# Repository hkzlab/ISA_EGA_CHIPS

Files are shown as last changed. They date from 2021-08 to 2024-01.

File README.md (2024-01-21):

# Enhanced Graphics Adapter

## Introduction

This board is and EGA clone based on a reversed **PA-WTEGA** card, based on the chipset by **CHIPS** (P82C435 + P82A436). 

The chipset should be compatible with EGA, CGA, MDA and Hercules standards.

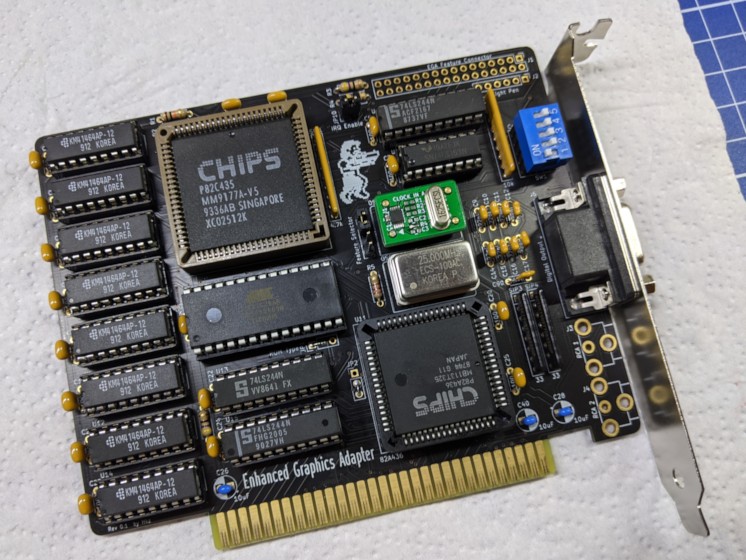
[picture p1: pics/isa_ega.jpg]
EGA CHIPS


### Disclaimer

I take NO responsibility for what happens if you decide to build and use this card. Your computer might crash, catch fire or be destroyed in other nasty ways.
You're encourauged to take what you deem fit from this, and use it in your projects!

### Configuration

The card as a bank of 5 dipswitches. Dipswitch 1-4 select the card video output mode, dipswitch 5 selects the IO address.

0 means switch open, 1 means closed.

* Jumpers 1-4:
    * 0-1-0-0: MDA Mode (main)
    * 1-0-0-1: CGA 40x25 (main)
    * 1-0-0-0: CGA 80x25 (main)
    * 0-1-1-1: EGA 200 lines (main)
    * 0-1-1-0: EGA 350 lines (main)
    * 1-1-1-1: CGA 40x25 (secondary)
    * 1-1-1-0: CGA 80x25 (secondary)
    * 1-1-0-1: EGA 200 lines (secondary)
    * 1-1-0-0: EGA 350 lines (secondary)
* Jumper 5:
    * 0: I/O address range in 3xx **default**
    * 1: I/O address range in 2xx

**NOTE:** The meaning of each combination is dependant on the bios of the card. This list was taken from the TEVA-2 card's manual.

TODO: Test all the combinations provided in the TEVA-2 card manual

### Functionalities

✅ means I tested the functionality and it works, ❌ means I tested the functionality and found issues, ? means that the functionality has yet to be tested.

* [✅] Display checkup with CheckIt (5154/EGA monitor)
* [✅] Display checkup with CheckIt (5153/CGA monitor)
* [?] Display checkup with CheckIt (5151/MDA monitor)
* [?] Display checkup with CheckIt (Hercules mode)
* [?] Feature Connector
* [?] Light pen input

## Bill of Materials

| Component | Qty | Type / Value |
| --- | --- | --- |
| **TODO** | | |

You can hardwire `JP1` pins 1-2 and `JP2` pins 2-3.

Connectors `RCA 1` and `RCA 2` are useless unless an expansion for the feature connector is used. You can leave them out.

### BIOS

This board was tested with [Phoenix Video Bios V1.02 for P82C435](bios/Phoenix_video_bios_PA-WTEGA_NMC27C256Q.BIN).

Burn it on a 27C256 and plug it in U10.

### Component substitutions

* U15 and U13 can be substituted with HCT equivalents
* U4 is an 'LS244 in the original card, I noticed an improvement in image stability with a MCE2VGA by using an 'F244 

## Known issues

### General issues

These are issues found with this board, but that are **also present in the original model** I cloned.

* Screen tearing detected in Commander Keen 4 and 5 (also happening on DOSBox configured for EGA, also note [here](http://nerdlypleasures.blogspot.com/2014/09/how-many-fps-dos-games-and-framerates.html): `The use of 35 frames, even in a 16-color game like Keen, demonstrates that ID was using VGA, not EGA, to develop the game` ). It can be fixed in-game by enabling the "Fix Jerky Motion" option in the config screen.
* Minor graphical glitches (flickering at top of the screen) during gameplay in Tom & Jerry CAT-astrophe.

### Rev 0.1

* Not really an issue as this is not present in the original card I cloned, but might be worth to add a jumper that can physically connect pin 2 of the DB9 connector to GND and not rely only on the jumper configuration, when using the card with a CGA monitor.

### Rev 0

* Some traces stub are left near the edge connector
* Some traces for sensitive sync signals are routed under the oscillators

## TODO

* Testing...

## Credits

Thanks to [Sergey Kiselev](https://github.com/skiselev) for his symbol/footprint library!

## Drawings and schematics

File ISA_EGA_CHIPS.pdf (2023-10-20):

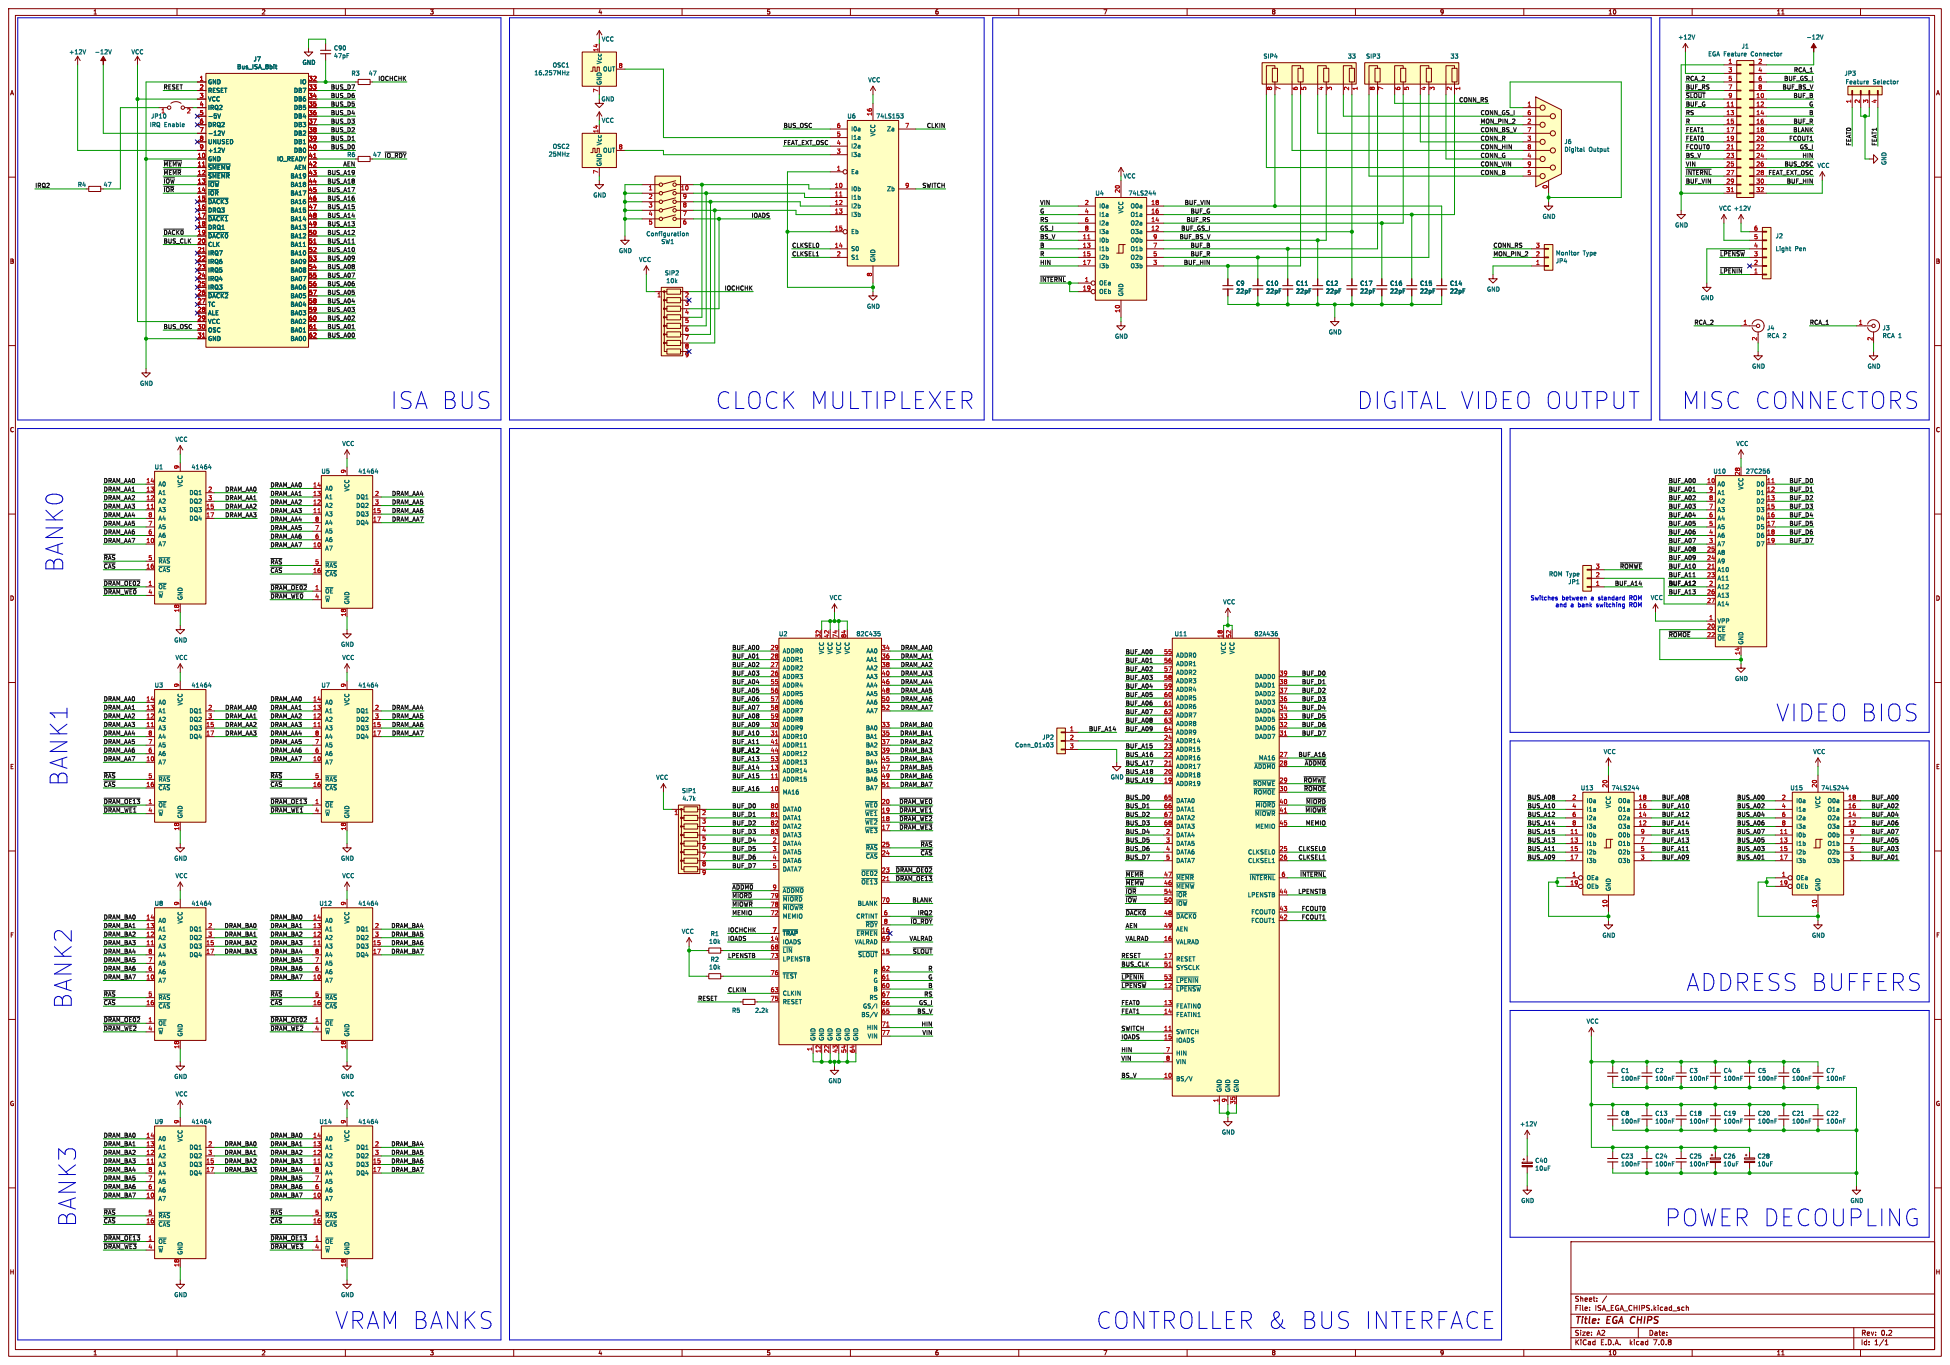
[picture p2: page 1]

J7 Bus_ISA_8bit GND 1 GND 10 ~{SMEMW} 11 ~{SMEMR} 12 ~{IOW} 13 ~{IOR} 14 ~{DACK3} 15 DRQ3 16 ~{DACK1} 17 DRQ1 18 ~{DACK0} 19 RESET 2 CLK 20

J1 EGA Feature Connector GND

J7 Bus_ISA_8bit
IRQ3 25 ~{DACK2} 26 TC 27 ALE 28 VCC 29 VCC 3 OSC 30 GND 31

JP3 Feature Selector GND

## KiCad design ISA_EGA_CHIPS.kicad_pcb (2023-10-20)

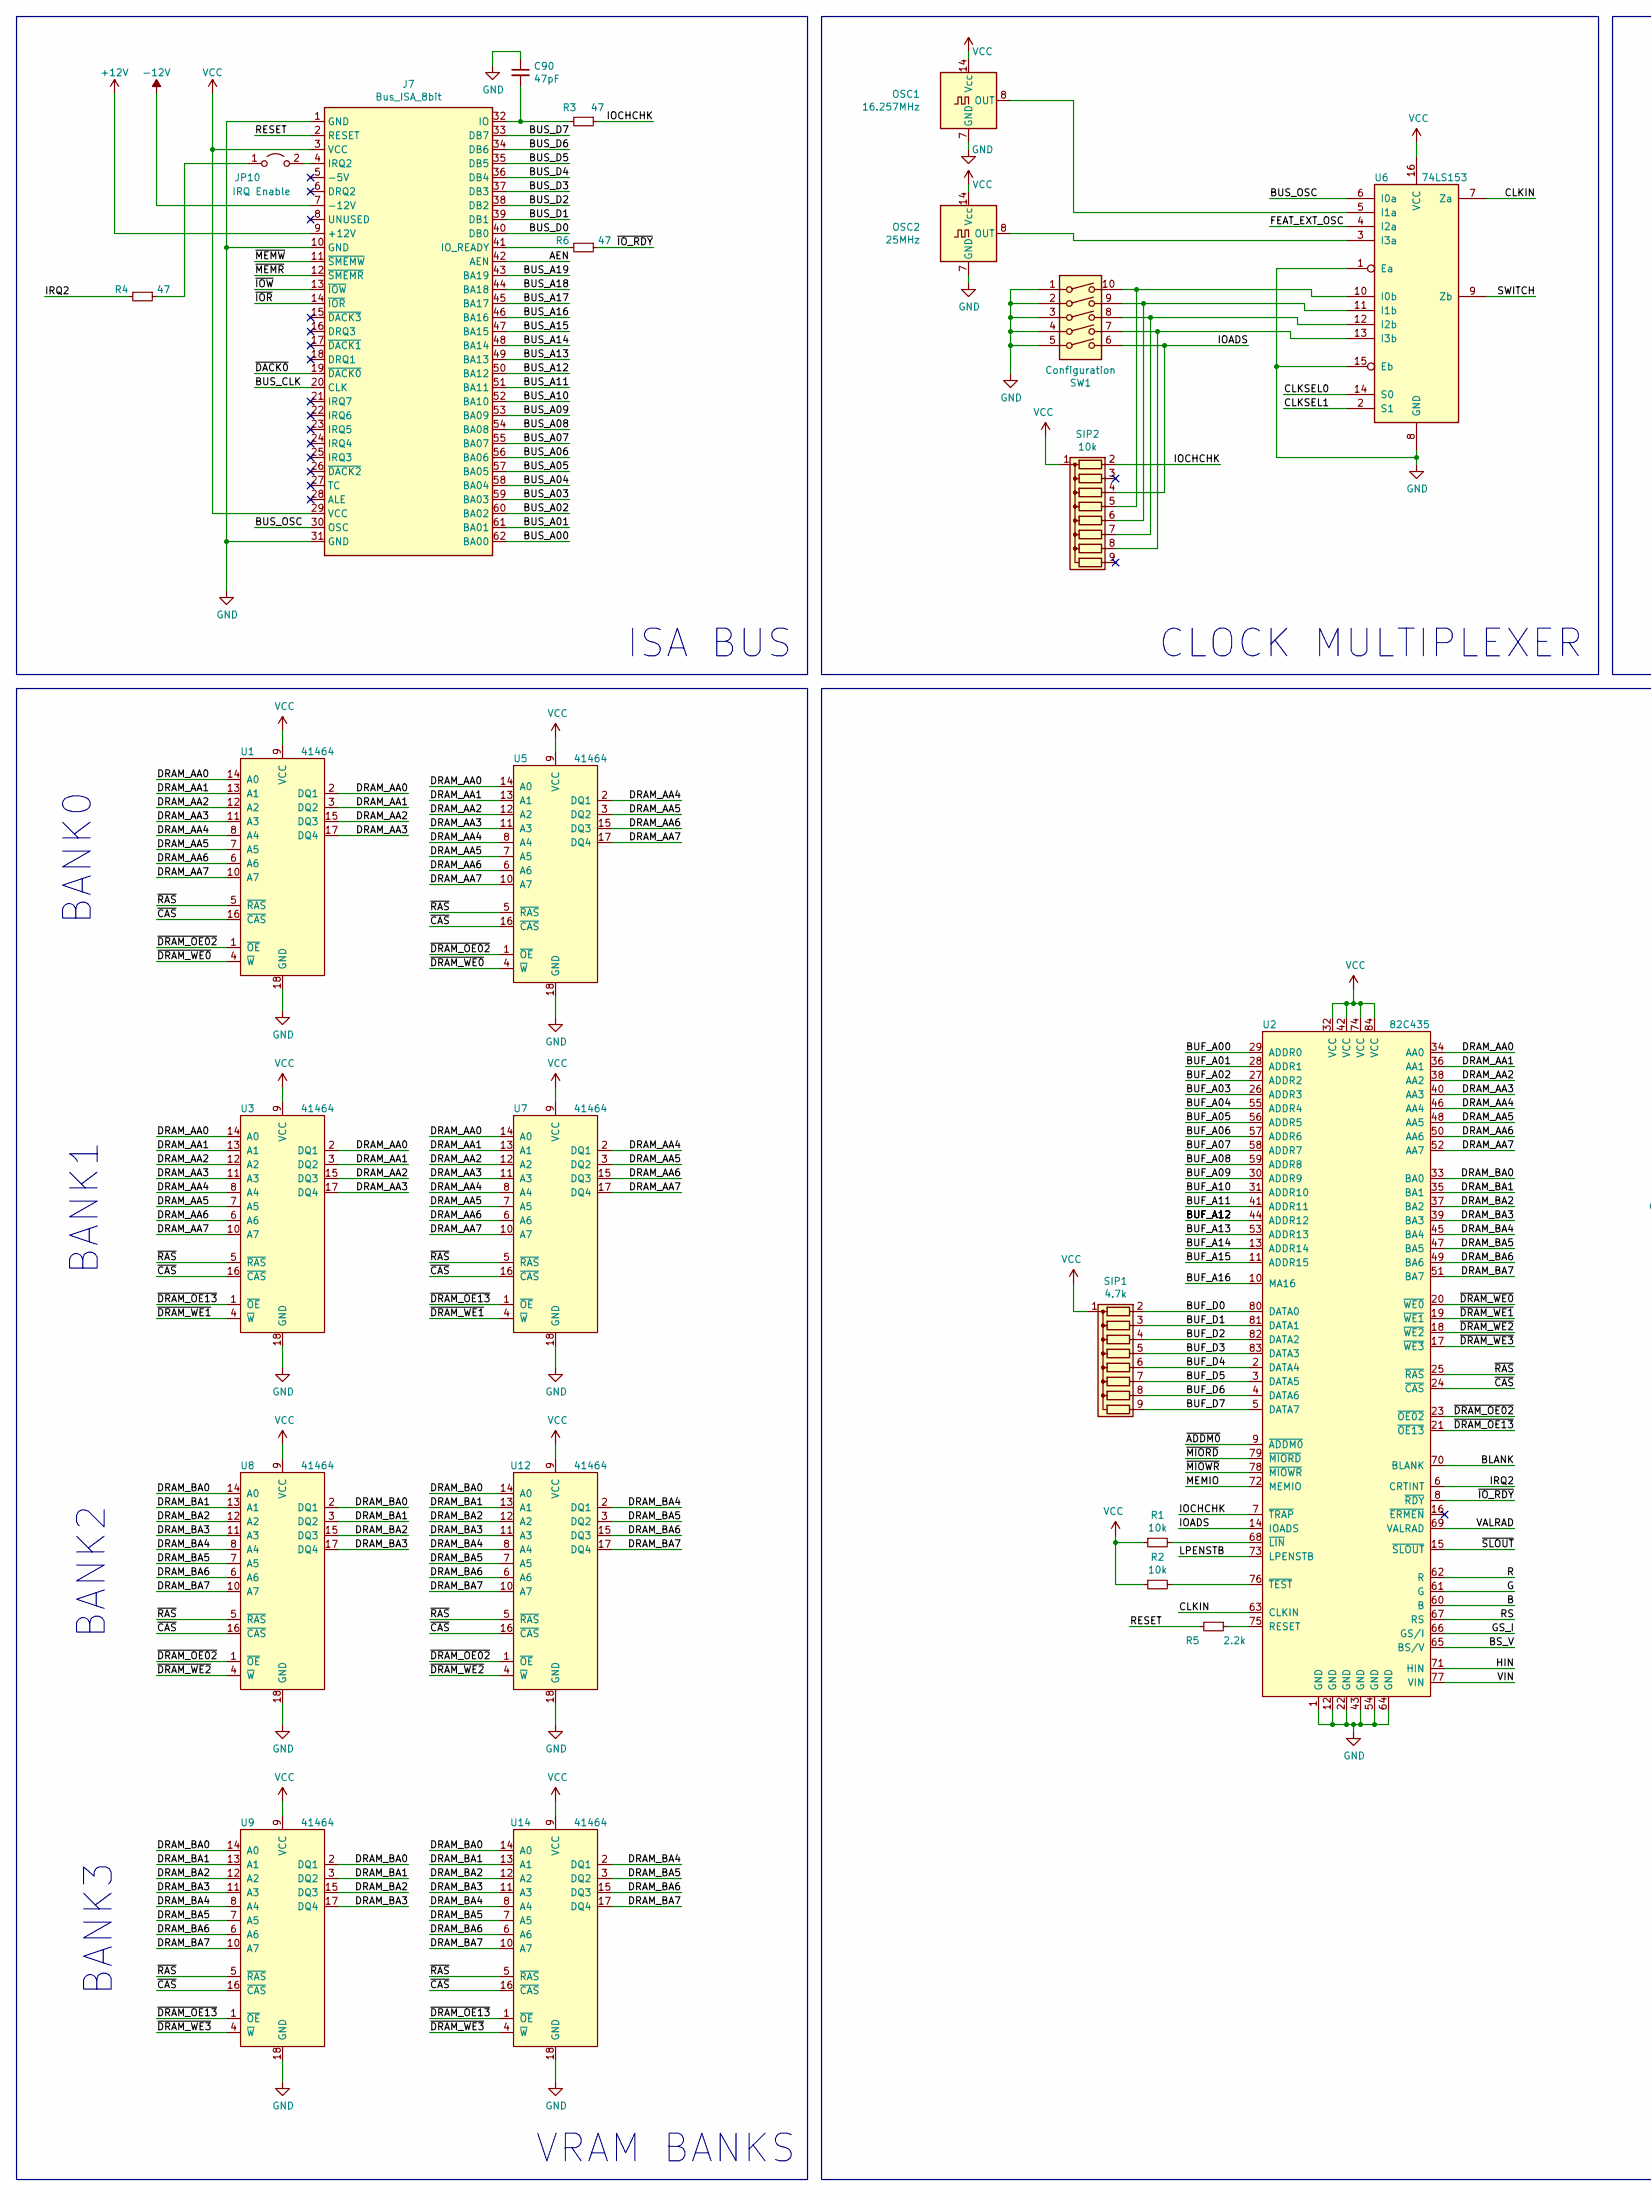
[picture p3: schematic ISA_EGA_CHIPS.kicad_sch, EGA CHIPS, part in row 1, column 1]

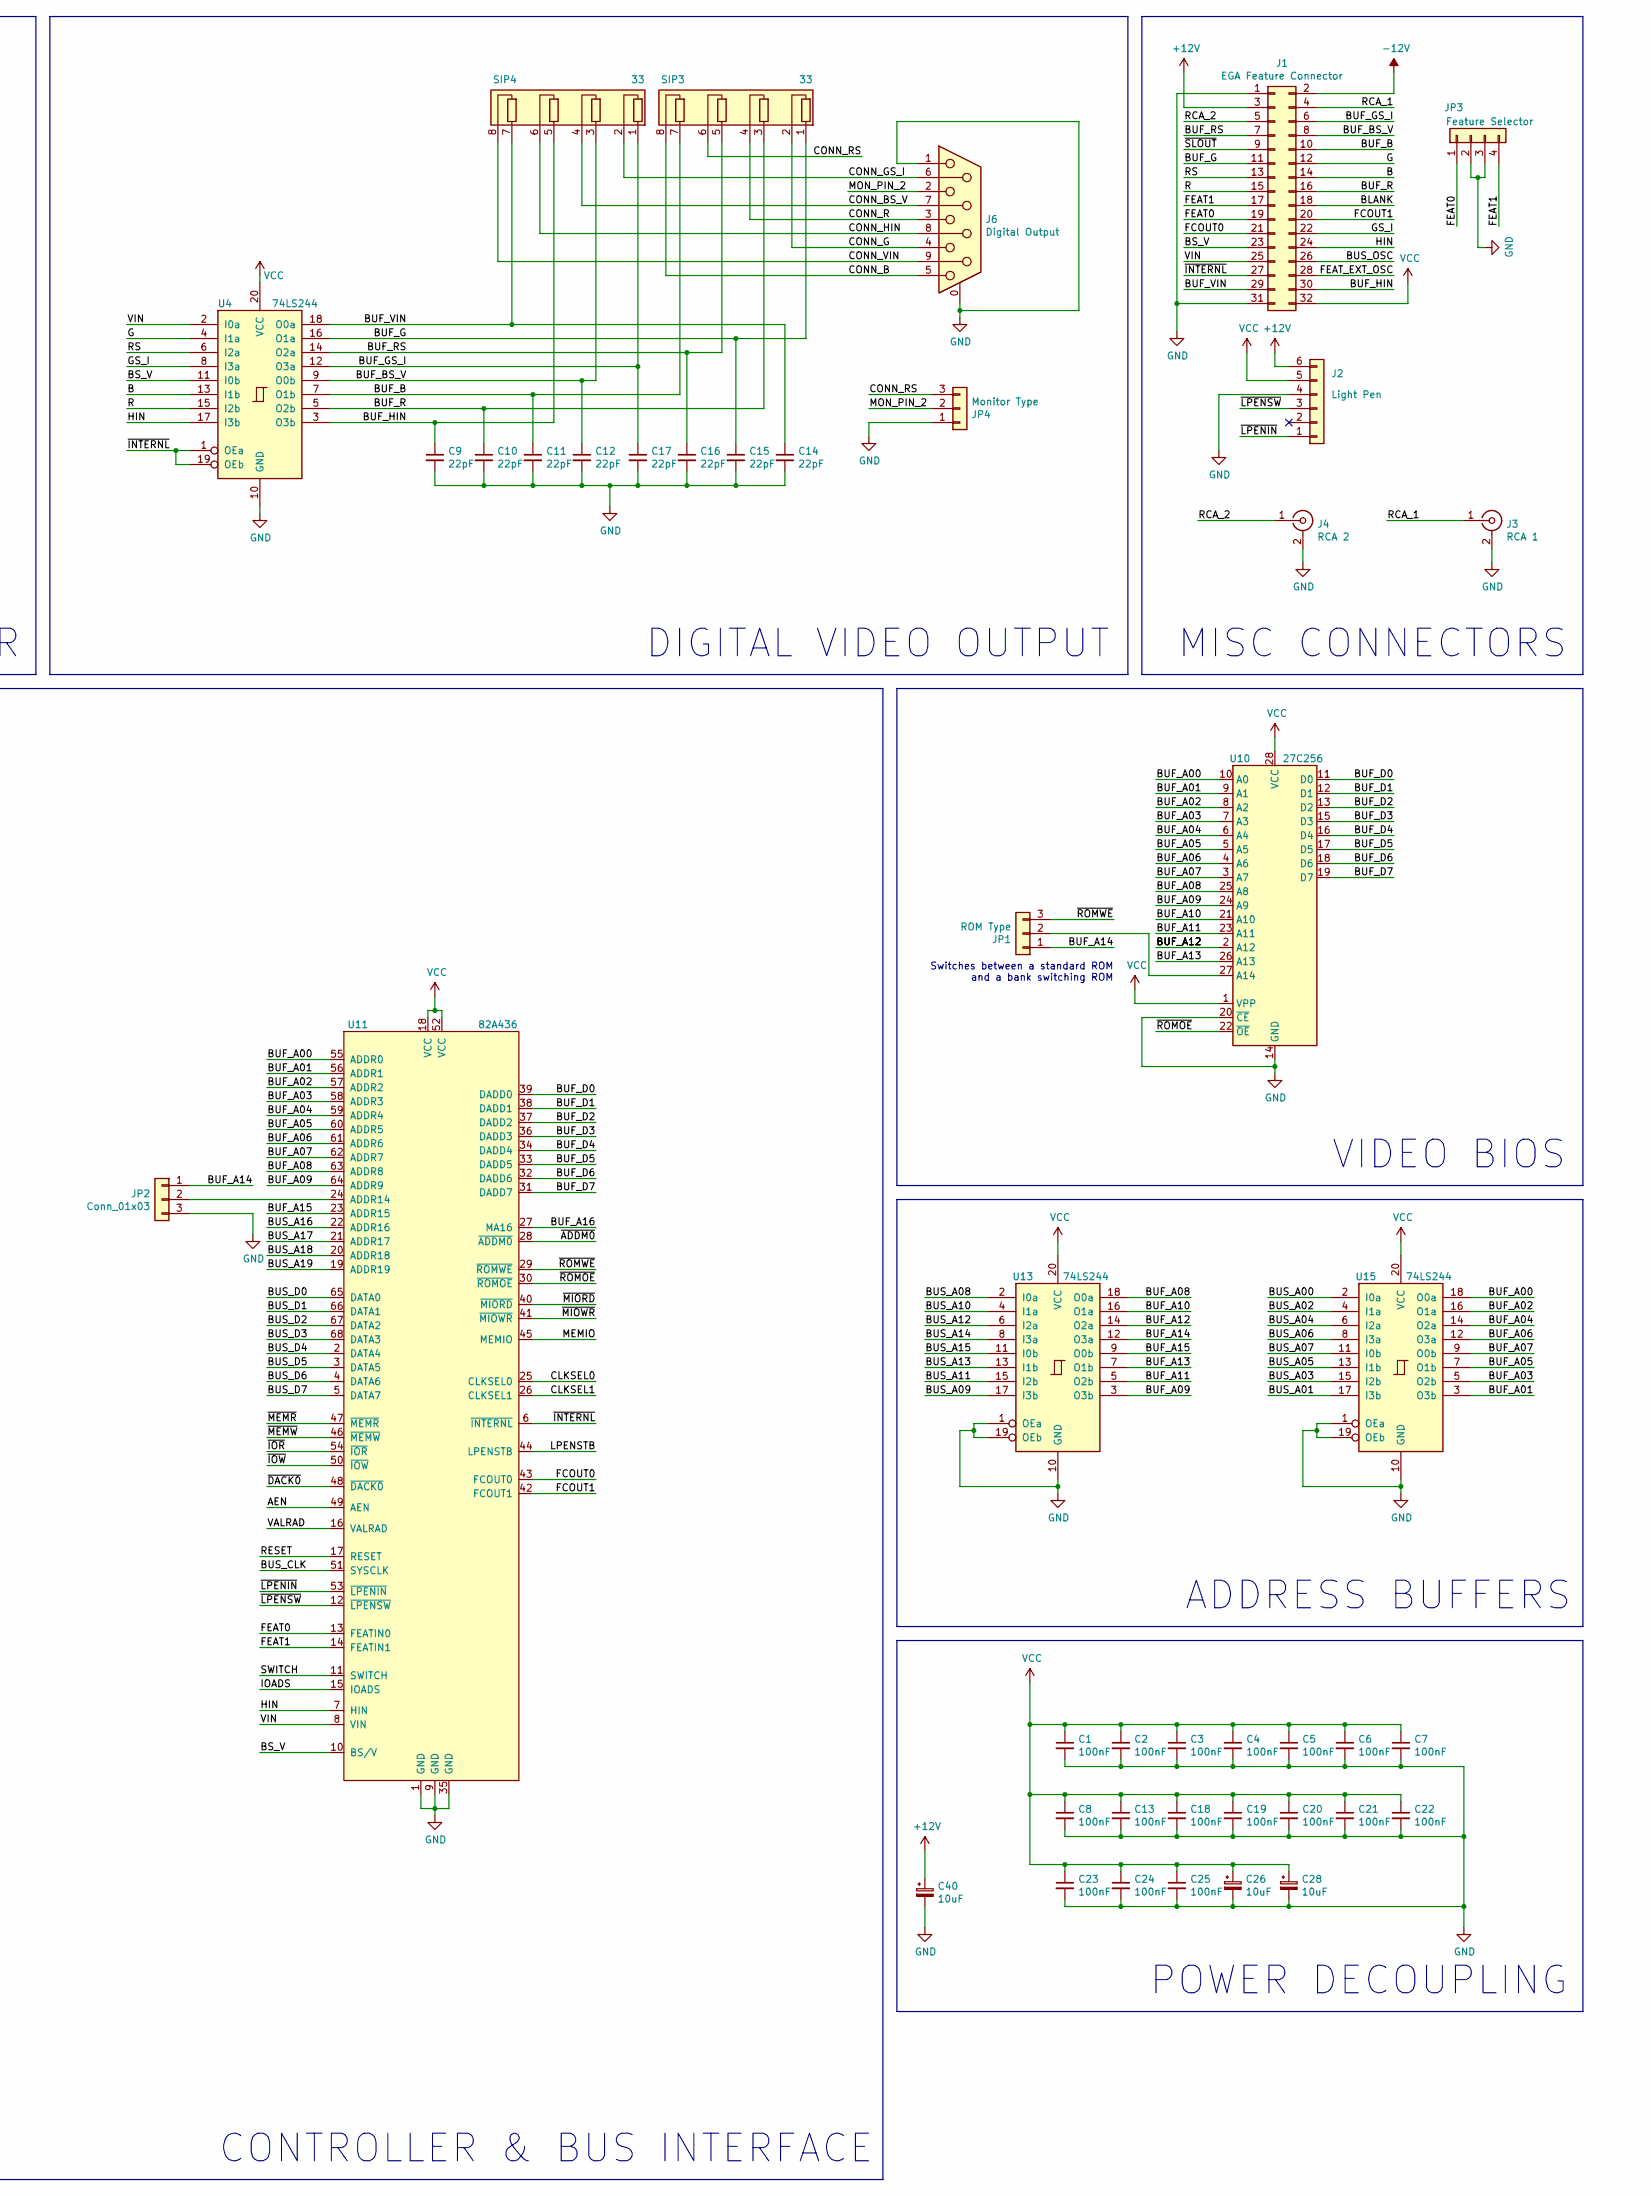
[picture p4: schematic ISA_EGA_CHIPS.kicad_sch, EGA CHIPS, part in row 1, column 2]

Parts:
C1, C2, C3, C4, C5, C6, C7, C8, C13, C18, C19, C20, C21, C22, C23, C24, C25: 100nF; C_Disc_D4.3mm_W1.9mm_P5.00mm
C9, C10, C11, C12, C14, C15, C16, C17: 22pF; C_Disc_D4.3mm_W1.9mm_P5.00mm
C26, C28, C40: 10uF; CP_Radial_D5.0mm_P2.50mm
C90: 47pF; C_Disc_D4.3mm_W1.9mm_P5.00mm
J1: EGA Feature Connector; PinHeader_2x16_P2.54mm_Vertical
J2: Light Pen; PinHeader_1x06_P2.54mm_Vertical
J3: RCA 1; Conn_RCA_Right
J4: RCA 2; Conn_RCA_Right
J6: Digital Output; DSUB-9_Female_Horizontal_P2.77x2.84mm_EdgePinOffset7.70mm_H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
J7: Bus_ISA_8bit; Conn_Edge_PCB_ISA8
JP1: ROM Type; PinHeader_1x03_P2.54mm_Vertical
JP2: Conn_01x03; PinHeader_1x03_P2.54mm_Vertical
JP3: Feature Selector; PinHeader_1x04_P2.54mm_Vertical
JP4: Monitor Type; PinHeader_1x03_P2.54mm_Vertical
JP10: IRQ Enable; PinHeader_1x02_P2.54mm_Vertical
OSC1: 16.257MHz; Oscillator_DIP-14-8
OSC2: 25MHz; Oscillator_DIP-14-8
R1, R2: 10k; R_Axial_DIN0207_L6.3mm_D2.5mm_P7.62mm_Horizontal
R3, R4, R6: 47; R_Axial_DIN0207_L6.3mm_D2.5mm_P7.62mm_Horizontal
R5: 2.2k; R_Axial_DIN0207_L6.3mm_D2.5mm_P7.62mm_Horizontal
SIP1: 4.7k; R_Array_SIP9
SIP2: 10k; R_Array_SIP9
SIP3, SIP4: 33; R_Array_SIP8
SW1: Configuration; DIP-10_W7.62mm_Socket
U1, U3, U5, U7, U8, U9, U12, U14: 41464; DIP-18_W7.62mm
U2: 82C435; PLCC-84_THT-Socket
U4, U13, U15: 74LS244; DIP-20_W7.62mm
U6: 74LS153; DIP-16_W7.62mm
U10: 27C256; DIP-28_W15.24mm
U11: 82A436; PLCC-68_THT-Socket

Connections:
+12V: C40.1, J1.3, J2.6, J7.9 (+12V)
-12V: J1.2, J7.7 (-12V)
/AEN: J7.42 (AEN), U11.49 (AEN)
/B: J1.14, U2.60 (B), U4.13 (I1b)
/BLANK: J1.18, U2.70 (BLANK)
/BS_V: J1.23, U2.65 (BS/V), U4.11 (I0b), U11.10 (BS/V)
/BUF_A00: U2.29 (ADDR0), U10.10 (A0), U11.55 (ADDR0), U15.18 (O0a)
/BUF_A01: U2.28 (ADDR1), U10.9 (A1), U11.56 (ADDR1), U15.3 (O3b)
/BUF_A02: U2.27 (ADDR2), U10.8 (A2), U11.57 (ADDR2), U15.16 (O1a)
/BUF_A03: U2.26 (ADDR3), U10.7 (A3), U11.58 (ADDR3), U15.5 (O2b)
/BUF_A04: U2.55 (ADDR4), U10.6 (A4), U11.59 (ADDR4), U15.14 (O2a)
/BUF_A05: U2.56 (ADDR5), U10.5 (A5), U11.60 (ADDR5), U15.7 (O1b)
/BUF_A06: U2.57 (ADDR6), U10.4 (A6), U11.61 (ADDR6), U15.12 (O3a)
/BUF_A07: U2.58 (ADDR7), U10.3 (A7), U11.62 (ADDR7), U15.9 (O0b)
/BUF_A08: U2.59 (ADDR8), U10.25 (A8), U11.63 (ADDR8), U13.18 (O0a)
/BUF_A09: U2.30 (ADDR9), U10.24 (A9), U11.64 (ADDR9), U13.3 (O3b)
/BUF_A10: U2.31 (ADDR10), U10.21 (A10), U13.16 (O1a)
/BUF_A11: U2.41 (ADDR11), U10.23 (A11), U13.5 (O2b)
/BUF_A12: U2.44 (ADDR12), U10.2 (A12), U13.14 (O2a)
/BUF_A13: U2.53 (ADDR13), U10.26 (A13), U13.7 (O1b)
/BUF_A14: JP1.1, JP2.1, U2.13 (ADDR14), U13.12 (O3a)
/BUF_A15: U2.11 (ADDR15), U11.23 (ADDR15), U13.9 (O0b)
/BUF_A16: U2.10 (MA16), U11.27 (MA16)
/BUF_B: C11.1, J1.10, SIP3.7 (R4.1), U4.7 (O1b)
/BUF_BS_V: C12.1, J1.8, SIP4.3 (R2.1), U4.9 (O0b)
/BUF_D0: SIP1.2 (R1), U2.80 (DATA0), U10.11 (D0), U11.39 (DADD0)
/BUF_D1: SIP1.3 (R2), U2.81 (DATA1), U10.12 (D1), U11.38 (DADD1)
/BUF_D2: SIP1.4 (R3), U2.82 (DATA2), U10.13 (D2), U11.37 (DADD2)
/BUF_D3: SIP1.5 (R4), U2.83 (DATA3), U10.15 (D3), U11.36 (DADD3)
/BUF_D4: SIP1.6 (R5), U2.2 (DATA4), U10.16 (D4), U11.34 (DADD4)
/BUF_D5: SIP1.7 (R6), U2.3 (DATA5), U10.17 (D5), U11.33 (DADD5)
/BUF_D6: SIP1.8 (R7), U2.4 (DATA6), U10.18 (D6), U11.32 (DADD6)
/BUF_D7: SIP1.9 (R8), U2.5 (DATA7), U10.19 (D7), U11.31 (DADD7)
/BUF_G: C15.1, J1.11, SIP3.1 (R1.1), U4.16 (O1a)
/BUF_GS_I: C17.1, J1.6, SIP4.1 (R1.1), U4.12 (O3a)
/BUF_HIN: C9.1, J1.30, SIP4.5 (R3.1), U4.3 (O3b)
/BUF_R: C10.1, J1.16, SIP3.3 (R2.1), U4.5 (O2b)
/BUF_RS: C16.1, J1.7, SIP3.5 (R3.1), U4.14 (O2a)
/BUF_VIN: C14.1, J1.29, SIP4.7 (R4.1), U4.18 (O0a)
/BUS_A00: J7.62 (BA00), U15.2 (I0a)
/BUS_A01: J7.61 (BA01), U15.17 (I3b)
/BUS_A02: J7.60 (BA02), U15.4 (I1a)
/BUS_A03: J7.59 (BA03), U15.15 (I2b)
/BUS_A04: J7.58 (BA04), U15.6 (I2a)
/BUS_A05: J7.57 (BA05), U15.13 (I1b)
/BUS_A06: J7.56 (BA06), U15.8 (I3a)
/BUS_A07: J7.55 (BA07), U15.11 (I0b)
/BUS_A08: J7.54 (BA08), U13.2 (I0a)
/BUS_A09: J7.53 (BA09), U13.17 (I3b)
/BUS_A10: J7.52 (BA10), U13.4 (I1a)
/BUS_A11: J7.51 (BA11), U13.15 (I2b)
/BUS_A12: J7.50 (BA12), U13.6 (I2a)
/BUS_A13: J7.49 (BA13), U13.13 (I1b)
/BUS_A14: J7.48 (BA14), U13.8 (I3a)
/BUS_A15: J7.47 (BA15), U13.11 (I0b)
/BUS_A16: J7.46 (BA16), U11.22 (ADDR16)
/BUS_A17: J7.45 (BA17), U11.21 (ADDR17)
/BUS_A18: J7.44 (BA18), U11.20 (ADDR18)
/BUS_A19: J7.43 (BA19), U11.19 (ADDR19)
/BUS_CLK: J7.20 (CLK), U11.51 (SYSCLK)
/BUS_D0: J7.40 (DB0), U11.65 (DATA0)
/BUS_D1: J7.39 (DB1), U11.66 (DATA1)
/BUS_D2: J7.38 (DB2), U11.67 (DATA2)
/BUS_D3: J7.37 (DB3), U11.68 (DATA3)
/BUS_D4: J7.36 (DB4), U11.2 (DATA4)
/BUS_D5: J7.35 (DB5), U11.3 (DATA5)
/BUS_D6: J7.34 (DB6), U11.4 (DATA6)
/BUS_D7: J7.33 (DB7), U11.5 (DATA7)
/BUS_OSC: J1.26, J7.30 (OSC), U6.6 (I0a)
/CLKIN: U2.63 (CLKIN), U6.7 (Za)
/CLKSEL0: U6.14 (S0), U11.25 (CLKSEL0)
/CLKSEL1: U6.2 (S1), U11.26 (CLKSEL1)
/CONN_B: J6.5, SIP3.8 (R4.2)
/CONN_BS_V: J6.7, SIP4.4 (R2.2)
/CONN_G: J6.4, SIP3.2 (R1.2)
/CONN_GS_I: J6.6, SIP4.2 (R1.2)
/CONN_HIN: J6.8, SIP4.6 (R3.2)
/CONN_R: J6.3, SIP3.4 (R2.2)
/CONN_RS: JP4.3, SIP3.6 (R3.2)
/CONN_VIN: J6.9, SIP4.8 (R4.2)
/DRAM_AA0: U1.2 (DQ1), U1.14 (A0), U2.34 (AA0), U3.2 (DQ1), U3.14 (A0), U5.14 (A0), U7.14 (A0)
/DRAM_AA1: U1.3 (DQ2), U1.13 (A1), U2.36 (AA1), U3.3 (DQ2), U3.13 (A1), U5.13 (A1), U7.13 (A1)
/DRAM_AA2: U1.12 (A2), U1.15 (DQ3), U2.38 (AA2), U3.12 (A2), U3.15 (DQ3), U5.12 (A2), U7.12 (A2)
/DRAM_AA3: U1.11 (A3), U1.17 (DQ4), U2.40 (AA3), U3.11 (A3), U3.17 (DQ4), U5.11 (A3), U7.11 (A3)
/DRAM_AA4: U1.8 (A4), U2.46 (AA4), U3.8 (A4), U5.2 (DQ1), U5.8 (A4), U7.2 (DQ1), U7.8 (A4)
/DRAM_AA5: U1.7 (A5), U2.48 (AA5), U3.7 (A5), U5.3 (DQ2), U5.7 (A5), U7.3 (DQ2), U7.7 (A5)
/DRAM_AA6: U1.6 (A6), U2.50 (AA6), U3.6 (A6), U5.6 (A6), U5.15 (DQ3), U7.6 (A6), U7.15 (DQ3)
/DRAM_AA7: U1.10 (A7), U2.52 (AA7), U3.10 (A7), U5.10 (A7), U5.17 (DQ4), U7.10 (A7), U7.17 (DQ4)
/DRAM_BA0: U2.33 (BA0), U8.2 (DQ1), U8.14 (A0), U9.2 (DQ1), U9.14 (A0), U12.14 (A0), U14.14 (A0)
/DRAM_BA1: U2.35 (BA1), U8.3 (DQ2), U8.13 (A1), U9.3 (DQ2), U9.13 (A1), U12.13 (A1), U14.13 (A1)
/DRAM_BA2: U2.37 (BA2), U8.12 (A2), U8.15 (DQ3), U9.12 (A2), U9.15 (DQ3), U12.12 (A2), U14.12 (A2)
/DRAM_BA3: U2.39 (BA3), U8.11 (A3), U8.17 (DQ4), U9.11 (A3), U9.17 (DQ4), U12.11 (A3), U14.11 (A3)
/DRAM_BA4: U2.45 (BA4), U8.8 (A4), U9.8 (A4), U12.2 (DQ1), U12.8 (A4), U14.2 (DQ1), U14.8 (A4)
/DRAM_BA5: U2.47 (BA5), U8.7 (A5), U9.7 (A5), U12.3 (DQ2), U12.7 (A5), U14.3 (DQ2), U14.7 (A5)
/DRAM_BA6: U2.49 (BA6), U8.6 (A6), U9.6 (A6), U12.6 (A6), U12.15 (DQ3), U14.6 (A6), U14.15 (DQ3)
/DRAM_BA7: U2.51 (BA7), U8.10 (A7), U9.10 (A7), U12.10 (A7), U12.17 (DQ4), U14.10 (A7), U14.17 (DQ4)
/FCOUT0: J1.21, U11.43 (FCOUT0)
/FCOUT1: J1.20, U11.42 (FCOUT1)
/FEAT0: J1.19, JP3.1, U11.13 (FEATIN0)
/FEAT1: J1.17, JP3.4, U11.14 (FEATIN1)
/FEAT_EXT_OSC: J1.28, U6.4 (I2a)
/G: J1.12, U2.61 (G), U4.4 (I1a)
/GS_I: J1.22, U2.66 (GS/I), U4.8 (I3a)
/HIN: J1.24, U2.71 (HIN), U4.17 (I3b), U11.7 (HIN)
/IOADS: SIP2.4 (R3), SW1.6, U2.14 (IOADS), U11.15 (IOADS)
/IOCHCHK: R3.1, SIP2.2 (R1), U2.7 (~TRAP)
/IRQ2: R4.2, U2.6 (CRTINT)
/LPENSTB: U2.73 (LPENSTB), U11.44 (LPENSTB)
/MEMIO: U2.72 (MEMIO), U11.45 (MEMIO)
/MON_PIN_2: J6.2, JP4.2
/R: J1.15, U2.62 (R), U4.15 (I2b)
/RCA_1: J1.4, J3.1 (In)
/RCA_2: J1.5, J4.1 (In)
/RESET: J7.2 (RESET), R5.2, U11.17 (RESET)
/RS: J1.13, U2.67 (RS), U4.6 (I2a)
/SWITCH: U6.9 (Zb), U11.11 (SWITCH)
/VALRAD: U2.69 (VALRAD), U11.16 (VALRAD)
/VIN: J1.25, U2.77 (VIN), U4.2 (I0a), U11.8 (VIN)
/~ADDM0: U2.9 (~ADDM0), U11.28 (~ADDM0)
/~CAS: U1.16 (~CAS), U2.24 (~CAS), U3.16 (~CAS), U5.16 (~CAS), U7.16 (~CAS), U8.16 (~CAS), U9.16 (~CAS), U12.16 (~CAS), U14.16 (~CAS)
/~DACK0: J7.19 (~DACK0), U11.48 (~DACK0)
/~DRAM_OE02: U1.1 (~OE), U2.23 (~OE02), U5.1 (~OE), U8.1 (~OE), U12.1 (~OE)
/~DRAM_OE13: U2.21 (~OE13), U3.1 (~OE), U7.1 (~OE), U9.1 (~OE), U14.1 (~OE)
/~DRAM_WE0: U1.4 (~W), U2.20 (~WE0), U5.4 (~W)
/~DRAM_WE1: U2.19 (~WE1), U3.4 (~W), U7.4 (~W)
/~DRAM_WE2: U2.18 (~WE2), U8.4 (~W), U12.4 (~W)
/~DRAM_WE3: U2.17 (~WE3), U9.4 (~W), U14.4 (~W)
/~INTERNL: J1.27, U4.1 (OEa), U4.19 (OEb), U11.6 (~INTERNL)
/~IOR: J7.14 (~IOR), U11.54 (~IOR)
/~IOW: J7.13 (~IOW), U11.50 (~IOW)
/~IO_RDY: R6.1, U2.8 (~RDY)
/~LPENIN: J2.1, U11.53 (~LPENIN)
/~LPENSW: J2.3, U11.12 (~LPENSW)
/~MEMR: J7.12 (~SMEMR), U11.47 (~MEMR)
/~MEMW: J7.11 (~SMEMW), U11.46 (~MEMW)
/~MIORD: U2.79 (~MIORD), U11.40 (~MIORD)
/~MIOWR: U2.78 (~MIOWR), U11.41 (~MIOWR)
/~RAS: U1.5 (~RAS), U2.25 (~RAS), U3.5 (~RAS), U5.5 (~RAS), U7.5 (~RAS), U8.5 (~RAS), U9.5 (~RAS), U12.5 (~RAS), U14.5 (~RAS)
/~ROMOE: U10.22 (~OE), U11.30 (~ROMOE)
/~ROMWE: JP1.3, U11.29 (~ROMWE)
/~SLOUT: J1.9, U2.15 (~SLOUT)
GND: C1.2, C2.2, C3.2, C4.2, C5.2, C6.2, C7.2, C8.2, C9.2, C10.2, C11.2, C12.2, C13.2, C14.2, C15.2, C16.2, C17.2, C18.2, C19.2, C20.2, C21.2, C22.2, C23.2, C24.2, C25.2, C26.2, C28.2, C40.2, C90.1, J1.1, J1.31, J2.4, J3.2 (Ext), J4.2 (Ext), J6.0 (PAD), J6.1, J7.1 (GND), J7.10 (GND), J7.31 (GND), JP2.3, JP3.2, JP3.3, JP4.1, OSC1.7 (GND), OSC2.7 (GND), SW1.1, SW1.2, SW1.3, SW1.4, SW1.5, U1.18 (GND), U2.1 (GND), U2.12 (GND), U2.22 (GND), U2.43 (GND), U2.54 (GND), U2.64 (GND), U3.18 (GND), U4.10 (GND), U5.18 (GND), U6.1 (Ea), U6.8 (GND), U6.15 (Eb), U7.18 (GND), U8.18 (GND), U9.18 (GND), U10.14 (GND), U10.20 (~CE), U11.1 (GND), U11.9 (GND), U11.35 (GND), U12.18 (GND), U13.1 (OEa), U13.10 (GND), U13.19 (OEb), U14.18 (GND), U15.1 (OEa), U15.10 (GND), U15.19 (OEb)
unnamed: C90.2, J7.32 (IO), R3.2
unnamed: J7.4 (IRQ2), JP10.2 (B)
unnamed: J7.41 (IO_READY), R6.2
unnamed: JP1.2, U10.27 (A14)
unnamed: JP2.2, U11.24 (ADDR14)
unnamed: JP10.1 (A), R4.1
unnamed: OSC1.8 (OUT), U6.5 (I1a)
unnamed: OSC2.8 (OUT), U6.3 (I3a)
unnamed: R1.2, U2.68 (~LIN)
unnamed: R2.2, U2.76 (~TEST)
unnamed: R5.1, U2.75 (RESET)
unnamed: SIP2.5 (R4), SW1.10, U6.10 (I0b)
unnamed: SIP2.6 (R5), SW1.9, U6.11 (I1b)
unnamed: SIP2.7 (R6), SW1.8, U6.12 (I2b)
unnamed: SIP2.8 (R7), SW1.7, U6.13 (I3b)
VCC: C1.1, C2.1, C3.1, C4.1, C5.1, C6.1, C7.1, C8.1, C13.1, C18.1, C19.1, C20.1, C21.1, C22.1, C23.1, C24.1, C25.1, C26.1, C28.1, J1.32, J2.5, J7.3 (VCC), J7.29 (VCC), OSC1.14 (Vcc), OSC2.14 (Vcc), R1.1, R2.1, SIP1.1 (common), SIP2.1 (common), U1.9 (VCC), U2.32 (VCC), U2.42 (VCC), U2.74 (VCC), U2.84 (VCC), U3.9 (VCC), U4.20 (VCC), U5.9 (VCC), U6.16 (VCC), U7.9 (VCC), U8.9 (VCC), U9.9 (VCC), U10.1 (VPP), U10.28 (VCC), U11.18 (VCC), U11.52 (VCC), U12.9 (VCC), U13.20 (VCC), U14.9 (VCC), U15.20 (VCC)

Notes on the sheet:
BANK3
BANK1
BANK0
CLOCK MULTIPLEXER
CONTROLLER & BUS INTERFACE
Switches between a standard ROM and a bank switching ROM
DIGITAL VIDEO OUTPUT
BANK2
VIDEO BIOS
ISA BUS
MISC CONNECTORS
VRAM BANKS
ADDRESS BUFFERS
POWER DECOUPLING

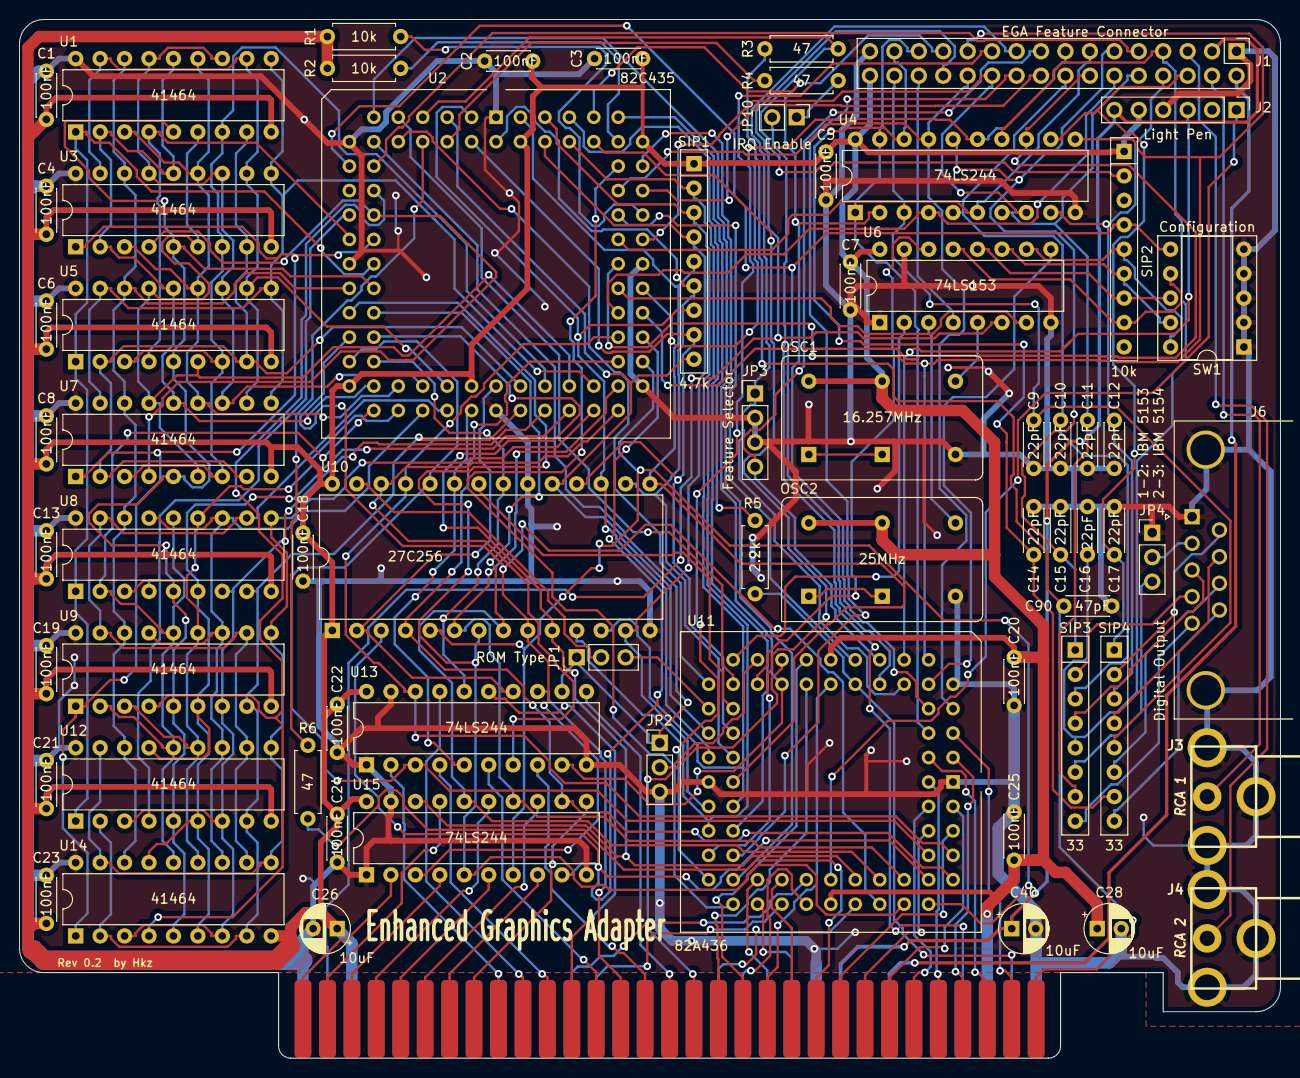
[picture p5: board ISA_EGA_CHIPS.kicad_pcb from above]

Board: 2 copper layers, 131.1 x 108.0 mm, 68 parts (0 on the bottom side), 158 nets.

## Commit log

2021-06-15 Added symbol for 41464
    [ISA_EGA_CHIPS.sch]
2021-06-15 Add RAM banks
    [ISA_EGA_CHIPS.sch]
2021-06-15 Added the other remaining ICs
    [ISA_EGA_CHIPS.sch]
2021-06-15 Added resistor packs
    [ISA_EGA_CHIPS.sch]
2021-06-15 Additional devices added to the schematic
    [ISA_EGA_CHIPS.sch]
2021-06-15 Add resistors
    [ISA_EGA_CHIPS.sch]
2021-06-15 Add jumpers
    [ISA_EGA_CHIPS.sch]
2021-06-15 More components
    [ISA_EGA_CHIPS.sch]
2021-06-15 Add first capacitors
    [ISA_EGA_CHIPS.sch]
2021-06-15 Added all missing components
    [ISA_EGA_CHIPS.sch]
2021-06-15 Add number for ISA bus connector
    [ISA_EGA_CHIPS.sch]
2021-06-15 Connected filter caps a powe supply in bus
    [ISA_EGA_CHIPS.sch]
2021-06-15 Add some connections
    [ISA_EGA_CHIPS.sch]
2021-06-15 Add connections for FEAT0/1
    [ISA_EGA_CHIPS.sch]
2021-06-15 Begin drawing wires for configuration switch decoding
    [ISA_EGA_CHIPS.sch]
2021-06-15 Removed two wires
    [ISA_EGA_CHIPS.sch]
2021-06-15 Completed the circuit for the multiplexer
    [ISA_EGA_CHIPS.sch]
2021-06-15 Moved connector
    [ISA_EGA_CHIPS.sch]
2021-06-15 Some more wires
    [ISA_EGA_CHIPS.sch]
2021-06-15 Some more wiring
    [ISA_EGA_CHIPS.sch]
2021-06-16 Fix IOCHCHK signal
    [ISA_EGA_CHIPS.sch]
2021-06-16 Fix IRQ2 signal
    [ISA_EGA_CHIPS.sch]
2021-06-16 Connect some more resistors
    [ISA_EGA_CHIPS.sch]
2021-06-16 Add bus connections
    [ISA_EGA_CHIPS.sch]
2021-06-16 Fix some more connections
    [ISA_EGA_CHIPS.sch]
2021-06-17 More connections
    [ISA_EGA_CHIPS.sch]
2021-06-17 More buffer connections
    [ISA_EGA_CHIPS.sch]
2021-06-17 Add another buffered address line
    [ISA_EGA_CHIPS.sch]
2021-06-17 Fix symbol, add other addresses
    [ISA_EGA_CHIPS.sch]
2021-06-17 More bus connections
    [ISA_EGA_CHIPS.sch]
2021-06-17 Some more connections
    [ISA_EGA_CHIPS.sch]
2021-06-17 Begin connecting data bus
    [ISA_EGA_CHIPS.sch]
2021-06-17 Add buffered data lines
    [ISA_EGA_CHIPS.sch]
2021-06-18 Connect more bus lines
    [ISA_EGA_CHIPS.sch]
2021-06-18 Add RGB to buffer connections
    [ISA_EGA_CHIPS.sch]
2021-06-18 Reorganize ram banks
    [ISA_EGA_CHIPS.sch]
2021-06-18 Connected addresses of first ram bank
    [ISA_EGA_CHIPS.sch]
2021-06-18 More RAM data bus connections
    [ISA_EGA_CHIPS.sch]
2021-06-18 Begin populating output connections
    [ISA_EGA_CHIPS.sch]
2021-06-18 First revision of the schematic
    [ISA_EGA_CHIPS.sch]
2021-06-18 Move around some resistors
    [ISA_EGA_CHIPS.sch]
2021-06-18 Add some notes
    [ISA_EGA_CHIPS.sch]
2021-06-18 Move around some components
    [ISA_EGA_CHIPS.sch]
2021-06-18 Fix some weirdness in the feature and light pen connector
    [ISA_EGA_CHIPS.sch]
2021-06-18 Add a jumper to disconnect IRQ2
    [ISA_EGA_CHIPS.sch]
2021-06-18 Add extra symbols and footprints
    [ISA_EGA_CHIPS.sch]
2021-06-18 Begin assigning some footprints
    [ISA_EGA_CHIPS.sch]
2021-06-18 Assign some more sockets
    [ISA_EGA_CHIPS.sch]
2021-06-18 Assigned footprints
    [ISA_EGA_CHIPS.sch]
2021-06-18 Place some components
    [ISA_EGA_CHIPS.kicad_pcb, ISA_EGA_CHIPS.sch]
2021-06-18 Place some more components
    [ISA_EGA_CHIPS.kicad_pcb]
2021-06-18 Placed all components
    [ISA_EGA_CHIPS.kicad_pcb]
2021-06-18 Draw basic power traces
    [ISA_EGA_CHIPS.kicad_pcb]
2021-06-18 First board render
    [ISA_EGA_CHIPS.kicad_pcb]
2021-06-19 Add silkscreen
    [ISA_EGA_CHIPS.kicad_pcb]
2021-06-19 Cleaned board, redone power traces
    [ISA_EGA_CHIPS.kicad_pcb]
2021-06-19 moved around some components
    [ISA_EGA_CHIPS.kicad_pcb]
2021-06-19 Redone some power traces
    [ISA_EGA_CHIPS.kicad_pcb]
2021-06-19 Change some more traces
    [ISA_EGA_CHIPS.kicad_pcb]
2021-06-19 Added keepout areas on connector
    [ISA_EGA_CHIPS.kicad_pcb]
2021-06-19 Resized keepout areas
    [ISA_EGA_CHIPS.kicad_pcb]
2021-06-19 Rerouted power traces
    [ISA_EGA_CHIPS.kicad_pcb]
2021-06-19 redraw some traces
    [ISA_EGA_CHIPS.kicad_pcb]
2021-06-19 Changed silkscreen
    [ISA_EGA_CHIPS.kicad_pcb]
2021-06-25 Add gerbers
    [ISA_EGA_CHIPS.kicad_pcb]
2021-07-05 Some track cosmetic fixes
    [ISA_EGA_CHIPS.kicad_pcb]
2021-07-05 Move EGA Feature Connector silkscreen
    [ISA_EGA_CHIPS.kicad_pcb]
2021-07-06 Other silkscreen fixes
    [ISA_EGA_CHIPS.kicad_pcb]
2021-07-06 Reroute some traces
    [ISA_EGA_CHIPS.kicad_pcb]
2021-07-06 Rerouted some traces
    [ISA_EGA_CHIPS.kicad_pcb]
2021-07-06 Better ground plane
    [ISA_EGA_CHIPS.kicad_pcb]
2021-07-06 Some more vias
    [ISA_EGA_CHIPS.kicad_pcb]
2021-07-08 Add some more grounding
    [ISA_EGA_CHIPS.kicad_pcb]
2021-07-08 Update grounding
    [ISA_EGA_CHIPS.kicad_pcb]
2021-07-08 Add more grounding
    [ISA_EGA_CHIPS.kicad_pcb]
2021-07-20 Add bio menace guy!
    [ISA_EGA_CHIPS.kicad_pcb]
2021-07-27 Add rev 0.1 gerbers
    [ISA_EGA_CHIPS.kicad_pcb]
2021-08-01 Add onboard connection for GND on pin 2
    [ISA_EGA_CHIPS.kicad_pcb, ISA_EGA_CHIPS.sch]
2021-08-01 Added some silkscreen notes
    [ISA_EGA_CHIPS.kicad_pcb]
2021-11-09 Updated KiCad url
2023-10-20 Import project into KiCad 7
    [ISA_EGA_CHIPS.kicad_pcb, ISA_EGA_CHIPS.kicad_sch, ISA_EGA_CHIPS.sch]
